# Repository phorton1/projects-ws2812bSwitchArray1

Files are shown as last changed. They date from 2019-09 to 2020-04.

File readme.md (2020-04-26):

# One Wire 3D Printed ws2812b Switch Array

This repository contains the STL and Fusion 360 files used to
create a **3D printed switch** which can be attached to a ws2812 LED
in an array or strip in order to create an array of buttons that
can be sensed by a microprocessor using only **one GPIO pin**.

There are **no multiplexers** involved, and there is **no X-Y grid**
of wires connected to the switches!

It also contains a specific test implementation and demonstration
program (sketch) using a Teensy 3.2 and a commonly available
8x32 LED array.  Below is link to a YouTube video showing the
demonstration program in action, and discussing briefly how the
project works:

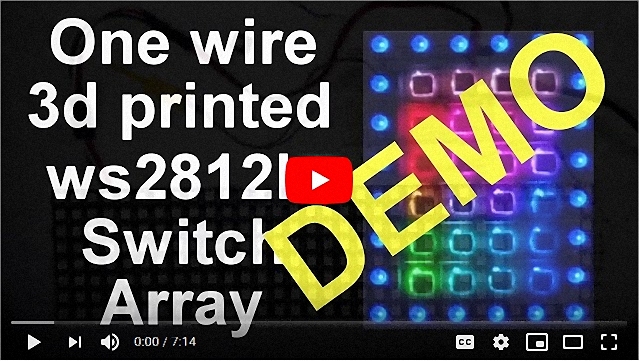
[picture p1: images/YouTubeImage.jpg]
YouTube Video Thumbnail (https://www.youtube.com/watch?v=zrMks7Vt0dI)


**THIS IS ONLY A PROOF OF CONCEPT DEMONSTRATION**

There are a couple of major caveats:

* The technology shown here *may* suffice for DIY purposes, but
  is probably not mature enough, yet, for use in commercial products.
  
* This project is not for the faint-of-heart.  The switches can be
  difficult to print and assemble, requiring the use of a 0.25 or
  smaller nozzle, lowered print speeds, and good filaments. Getting
  the size, and bends, in the guitar string spring/contacts takes
  a lot of patience and at least a few tries.
  
In this repository you can find the STL and Fusion 360 files for
the 3D printed swtiches, along with the source code for the
demonstration program.   Please see the readme files in
the subdirectories for more information:

   [/stl - PRINTING THE SWITCHES](stl/readme.md)

   [/src - THE DEMO PROGRAM](src/readme.md)

This **github repository** is the authorative source of information about this project.
There is also a Hackaday project at [One Wire 3D Printed ws2812 Switch Array](https://hackaday.io/project/167696-one-wire-3d-printed-ws2812b-switch-array)
and a Thingiverse page at [ws2812b Switch](https://www.thingiverse.com/thing:3870539) that contains mostly
the same information, in slightly different presentations.

## HOW THEY WORK

The concept takes advantage of the fact that such LEDs arrays are
fed with a single serial data stream that is successivly passed
down from the first LED in the array to each LED in turn.

Each LED "eats" 24 bits of color information before it begins passing
the subsequent bits onto the next LED.  We also take advantage of the
fact that in the ws2812b protocol every bit, whether a "zero" or a "one"
bit, consists of at least one "rising edge" delivered to each LED.

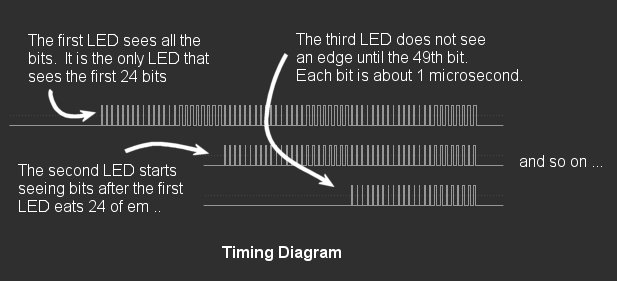
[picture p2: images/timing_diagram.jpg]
Timing Diagram


Thus, by attaching a switch to the DIN (data in) pin of each LED, and
connecting all of those switches to a single common wire back to the
CPU, based on the timing, we can determine which switch, if any, is
pressed during a refresh cycle.

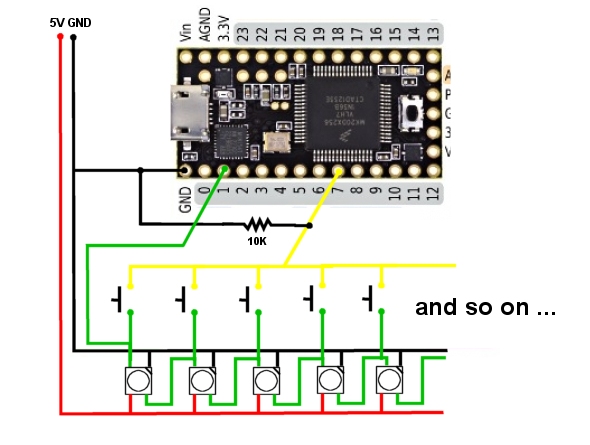
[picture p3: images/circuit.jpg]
Circuit Diagram


The technique can only detect the FIRST button pressed in such an array.
It cannot detect multiple simultaneous button presses. There are other
limitations and issues that will be discussed below.

This example works with an interrupt on the Teensy to measure the
amount of time it takes, from the beginning of a refresh cycle until
the interrupt is triggered to determine which button is pressed.
On the Teensy 3.2 at 90Mhz using the WS2812Serial library, it takes just
about 30 microseconds per LED.  So, basically, we just divide the
number of microseconds to the interrupt by 30 and we get the "button number"
of the (first/earliest) button that is pressed.

This works well in the limited test program, which makes use of the
WS2812Serial, non-blocking, ws2812b library, which in turn uses DMA and
a hardware UART to send the bits to the LEDs. Because it is non-blocking,
and it leaves interrupts enabled, we can use such an approach.

## THIS IDEA SHOULD WORK WITH ANY CPU and/or LIBRARY

Although this demonstration uses the WS2812Serial library and Teensy 3.2,
this concept should be usable with ANY cpu that is currently used to
control such a ws2812b, or other similar, addressable LED array, including
Arduinos and Raspberry Pi's.

**It should also work with different sized arrays, LED strips, circles, etc**

An earlier demonstration of this idea, that used a synchronous detection
approach is available on my previous hackaday page [Why Doesn't Someone Make a ws2812 Switch Array?](https://hackaday.io/page/6514-why-doesnt-someone-make-a-ws2812b-switch-array)

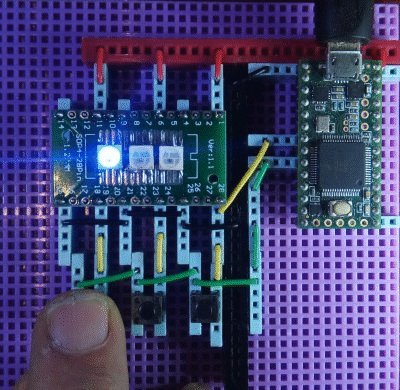
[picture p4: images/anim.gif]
Previous Animation (https://hackaday.io/page/6514-why-doesnt-someone-make-a-ws2812b-switch-array)


In that example, and for other ws2812b libraries, like the FastLEd or Adafruit
NeoPixel libraries, that send the bits to the LEDS synchronously (one by
one via the CPU), an alternative approach can be used if interrupts are
disabled, or if so desired for some other reason.

In that case the low level procedure that sends the bits to the LEDs just
has to have access to a counter that tells it, at any time, which LED
it is sending bits to (each LED takes 24 bits). It can then check the
input line just after it sends out the rising edge of any, or all,
of the bits to each LED, and return the counter as the "number" of
the button that is pressed.

## 3D Printed Switch Issues

Requirements:

* for FDM printers, I think a 0.25 or smaller nozzle may be needed
* a 0.010 high "E" guitar string
* some hemostats or small needle nosed pliers to bend the guitar string

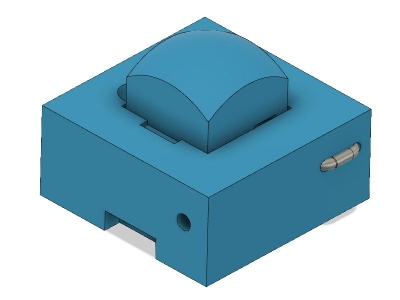
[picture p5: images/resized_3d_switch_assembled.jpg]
3D Switch


### NOZZLE

When I started 3D printing a month or two ago, I immediately went to ebay
and bought a number of inexpensive replacement 0.40 brass nozzles, figuring
I would need them.  At that time I also picked up a variety of different sized
(cheap) stainless steel nozzles for the printer. I think I paid $20 or so for 10
stainless nozzles from 1.0 down to 0.20 mm in size.  I am **not** an expert
at 3D printing and this was my first attempt with a 0.20 nozzle.

You *may* be able to print these with a 0.40 nozzle.  I dunno. I never tried.
I actually started this project by changing the nozzle on the printer and
trying to print really small things for the first time.

### PRINTING TINY THINGS

There are only two printed parts.  The **base** and the **top**.

I will be honest and tell you it was not easy. I found the entire process to
be very finicky.  What would work with one filament would then fail miserably
when I tried it with a different filament.  Or I could get it to print one
switch "base" or "top", but then when I tried (in SlicePE) to print 8 or 16
of the same things, it would fail.  I had to mess around and experiment with
brims and supports, and trying to print the parts every which way.

The current Fusion 360 and STL files are tuned so that they work with my
printer and settings to correctly hold the 0.010 guitar string and 22 guage
wire, so that the switches properly "snap" onto the ws2812 LEDs, and so that
they fit together in an array.

Your mileage may vary!

### THE GUITAR STRING

The other thing is the "spring" and "contact" made out of a single small
piece of a 0.010 guitar string.   I don't have access to any hardware stores
and so I was forced to make do with what I have here on the boat.  As a guitar
player I have bunch of new and old used guitar strings laying around.  I played
around with the different strings E .... B ..... the wire wound G string ... and
found that the **high E string** had just about the right amount of springyness to
work in such a button.

**Cutting and Bending the Guitar String just right is the most difficult part**

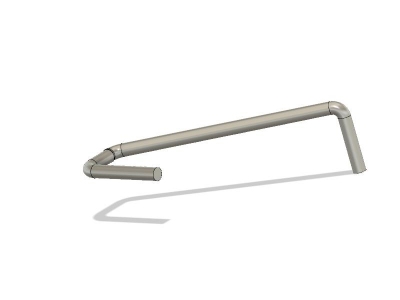
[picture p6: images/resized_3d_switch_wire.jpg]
The Wire


I went through over 20 iterations of the design trying to come up with a way
to (a) make a springy switch and (b) make contact with the DIN pin on each LED,
and (c) connect all the switches together, before narrowing in on this approach.

This approach uses a single small piece of guitar string to meet all three requirements.
The piece of guitar string is both the "spring" for the switch, as
well as the "contact" for the DIN pin, as well as the "connector" to a piece of
22 guiage wire.

Thus it is the most critical piece in the assembly of the switches.

This little piece of wire has to do a lot of work, and must be cut and
bent just right in order to function.

* it has to have a little angle in it so that it acts as a spring to push the button up.
* the other end must be bent and cut just right so that when it is pushed down it makes
  contact with the LED DIN pin
* the holes on the printed switch must be aligned so that the 22 guage wire
  just barely makes conact with the guitar spring when the switch is in an
  "open" position.
  
As I was experimenting, by the time I got it down to one piece of guitar string,
by coincidence, I found that, if the holes were positioned JUST RIGHT, that I
could slide a normal 22 guage solid copper breadboard wire into the holes and they
would make contact with the guitar string in each switch.

In fact, when you press the switch, it pushes down the guitar string down,
re-enforcing the contact with the 22 guage wire first as it then bends down
further to make contact with the DIN pin on the LED.  In this latest (posted)
version of the switch, the 22 guage wire should fit easily into the switches
and when you press the button it should sort of "lock" the 22 guage wire in.

If you find you have to force the 22 guage wire into the hole then you'll
either need to change your print settings, or even go so far as to modify the
design in the Fusion 360 files yourself.

Once again, this is just a "proof of concept". I have some ideas, below,
for future development of more robust and usable switches, possibly involving
printed circuit boards and/or other manufacturing processes..

### ISSUES AND FUTURE IDEAS

* At a minimum each switch needs a diode between the DIN pin on the LED and the
common wire back to the CPU.  Otherwise (with the current circuit) if two buttons
are pressed simultaneously, it connects the two DIN pins, and messes up the serial
data stream.  The switch detection algorithm still works, but the LED array itself
may flash or display the wrong colors as a result of this short circuit.

* I would like to figure out how to "gate" the interrupt signal at each switch
using some kind of a small simple SMD device so that once an interrupt fires,
THAT pin is then disabled from sending any more interrupts.   That would allow
for the detection of multiple simultaneous keypresses.

* I want to explore the use of the ws2812b **2020** LED and custom printed PCB's,
possibly flexible.  The 2020 LED is only 2x2 mm and that would allow a higher
density of switches in the array.  Instead of a 3D printed 10mm switch, I would
then consider tooling up for a (an array of) 4x4 mm soft silicon switch(es).

By the way, this is all (still) nominally part of the
[rPi bare metal Guitar Rig](https://hackaday.io/project/165696-rpi-bare-metal-vguitar-rig) project.
My idea here is to create a **foot-touch-pad** ... like putting a touchscreen on the floor and
using it with your feet.  There are no such (inexpensive) commercially available foot pads,
and there is no way I'm gonna put a $700 iPad on the ground, face up, at a gig, in a bar-room
situation.   I'd like to be able to also get some feedback (i.e. the LED display) about
things like volume levels, patch selections, song position, etc, so I am thinking that a
general purpose controller of this sort could be handy.   It might also be useful for
other purposes, including for use by disabled persons, so it is a project I will continue
to explore.

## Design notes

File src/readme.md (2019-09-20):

# The Software

This directory includes the demo program that I show in the
[One Wire 3D Printed ws2812 Switch Array Demo](https://www.youtube.com/watch?v=qGlxH-YuUHk)
YouTube Video.

If you happen to have a Teensy 3.2 and an 8x32 LED array, then you
*might* be interested in trying to rebuild my exact demo.

**Proabably Not!!** :-)

Really, probably all you really want to know is **how it works** and
**how can I make it work for me** ... :-)

So, although I put a ton of effort into the demo program, sigh, to
implement the color picker and a full blown (although integer)
desktop calculator application :-) all that is actually interesting
in this part of the project is the very small **ws2812SwitchArray class**
that is merely a very thin wrapper around *Paul Stoffregen's*
**WS2812Serial** library.

**IMPORTANT NOTE:**  In the YouTube video I say that I'm using the FastLed
library.  I am not.

I am using **Paul Stoffregen's non-blocking WS2812Serial** library !!

Please support the Teensy and Paul and their website at https://www.pjrc.com!!

## My ws2812SwitchArray class

Here's pretty much the whole H file:

```
#define NUM_ROWS  8
#define NUM_COLS  32
#define NUM_LEDS (NUM_ROWS * NUM_COLS)

class ws2812SwitchArray
{
public:
    
    ws2812SwitchArray();  
    ~ws2812SwitchArray()  {}
    
    void init();
    void showLeds();
 
    void setPixel(int pixel_num, int color);
    void setPixel(int row, int col, int color);
    byte *getDrawingMemory();
    
    int buttonPressed();
        // called at the top of the loop, before the next
        // call to showLeds() and after the previous one,
        // returns the one based button that was pressed,
        // if any.
        
protected:

    static int button_pressed;                     // button pressed 
    static elapsedMicros show_time;                // microseconds since showLeds started
    static void buttonIRQ();

};
```

You call **init()** from your sketch's *setup()* method.

The **setPixel()** and **getDrawingMemory()** methods are just pass
throughs to the the "base class" (global static) leds stuff.
These are used to set the color bytes into arrays in memory.

Each time through your *loop()* method, at some point, you call
**showLeds()** to send the pixels to the array.

Then next time through the loop (at the top) you call **buttonPressed()**
to see if a button was presed during the previous call to showLeds().

*That's pretty much it.*

You may need to modify the number of rows and number of columns to
match your array or strip.   Other details, like the PINS used are
in the CPP file, which is also shown here in nearly it's entirety:

```
#define LED_PIN         1       // write to DIN of first pixel
#define SWITCH_PIN      7       // sense if a button is pressed

// Usable LED pins:
//   Teensy LC:   1, 4, 5, 24
//   Teensy 3.2:  1, 5, 8, 10, 31   (overclock to 120 MHz for pin 8)
//   Teensy 3.5:  1, 5, 8, 10, 26, 32, 33, 48
//   Teensy 3.6:  1, 5, 8, 10, 26, 32, 33

#define MICROS_PER_LED      30      // microseconds per pixel before it sees rising edge
#define MICROS_TO_0TH_LED   475     // microseconds until the first led sees rising edge

byte drawingMemory[NUM_LEDS*3];         //  3 bytes per LED
DMAMEM byte displayMemory[NUM_LEDS*12]; // 12 bytes per LED
WS2812Serial leds(NUM_LEDS, displayMemory, drawingMemory, LED_PIN, WS2812_GRB);

elapsedMicros ws2812SwitchArray::show_time = 0;       // microseconds since showLeds started
int ws2812SwitchArray::button_pressed = 0;            // one based button pressed

ws2812SwitchArray::ws2812SwitchArray() 
{}

void ws2812SwitchArray::init()
{
    pinMode(SWITCH_PIN,INPUT_PULLDOWN);
    attachInterrupt(digitalPinToInterrupt(SWITCH_PIN), buttonIRQ, RISING);
    leds.begin();
}

byte *ws2812SwitchArray::getDrawingMemory()
{
    return drawingMemory;
}

void ws2812SwitchArray::showLeds()
{
    button_pressed = 0;
    show_time = 0;
    leds.show();
}

void ws2812SwitchArray::setPixel(int pixel_num, int color)
    // convenience method
{
    leds.setPixel(pixel_num, color);
}

void ws2812SwitchArray::setPixel(int row, int col, int color)
    // handles interleaving of my led array
{
    if (col % 2) row = NUM_ROWS - 1 - row;
    leds.setPixel(col * NUM_ROWS + row,color);
}

int ws2812SwitchArray::buttonPressed()
{
    return button_pressed;
}

void ws2812SwitchArray::buttonIRQ()
{
    if (!button_pressed)
    {
        int the_time = show_time;
        
        #if 0
            static int counter = 0;
            counter++;
            Serial.print(counter);
            Serial.print(" - IRQ encountered micros=");
            Serial.println(the_time);
        #endif

        button_pressed = ((the_time-MICROS_TO_0TH_LED) / MICROS_PER_LED) + 1;
    }
}
```

In order to calibrate this the first time, I did some measurements to
come up with values for *MICROS_TO_0TH_LED* and *MICROS_PER_LED* by including
the **#if 0** section of code in **buttonIRQ()**

Once more, the code goes like this:

(1) at some point **showLeds()** is called, and it sets both the elapsedMicros "show_time"
and one-based integer variable "button_pressed" to zero.

(2) Then (if a button is pressed) **the IRQ is triggered** and it figures out
which button was pressed and sets that into a button_pressed.

(3) **The client calls buttonPressed()** from their loop() method, at the top
of the next time through their loop, before they make the next showLeds()
call.

There's a bit of debouncing and higher level logic in the
**onLoop()** method in [demo_ui.cpp](demo_ui.cpp), but apart from
that, this is basically how it works.

And finally, please note a couple of other things.

* **This is only a demo**.  It is not intended to be a general purpose library
* The *technique* (but not necesarily the *CODE*) here should work with other CPUs and Libraries
* As an alternative to Interrupts and counting microseconds, for libraries using synchronous
  output or which disable interrupts, you'll have to get down to the low level output method
  and check for a high signal on the input line just after it sends out the rising edge(s).
  At that point, since you are sending out pixels! you should already KNOW what pixel you
  are talking to!

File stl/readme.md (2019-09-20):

# 3D Printed Switches for ws2812b LEDs

This directory contains the STL files for the switches used in the
[One Wire 3D Printed ws2812 Switch Array](../readme.md) project, along
with the **printing** and **assembly** instructions.  You can find
the Fusion 360 files [HERE](https://github.com/phorton1/projects-ws2812bSwitchArray1/tree/master/fusion).

Since they are so small, printing them boils down to an exersize in
trying to print really small things on your printer.

3d_switch
3d_switch_wire

The switch uses a piece of wire (I used a 0.010 high "E" guitar string)
as the spring, contact, and connector.

**The hardest part of the whole project** is to **cut** and **bend** those
pieces of wire **correctly and repeatably**.

It took quite a few tries, but I found that after a while I could do it
reliably and repeatedly

## QUALITY CONTROL

I suggest building one or two, then building 4 or 5, before gearing up for
a production run if you want to try to print and build a lot of these.

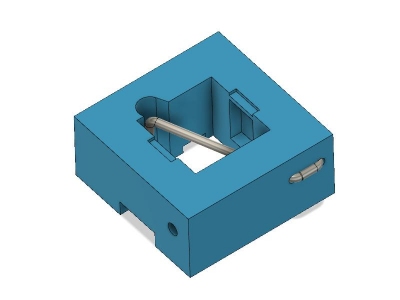
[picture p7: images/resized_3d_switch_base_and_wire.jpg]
3d_switch


Also I recommend assembling and testing them one at a time before stringing
them together into a big array. As I assembled and tested them, I used
three "bins" for the testing results:

* the **"A" bin** contained switches that worked the first time I tried them,
 were nice and springy, and which worked at least a few times reliably,
 in a row, without any gliches.
* the **"B" bin** contained switches that were almost right, but which had **one**
 issue that could probably be solved by popping off the top and tweaking the
 guitar string, but which probably did not need the entire guitar string to
 be replaced, and ...
* the **"C" bin** which contained switches that I should have known would not
 work in the first place.  These are usually ones where the guitar string
 was not bent correctly to begin with, got bent out of shape during
 the assembly process itself, or on which I *missed* the final critical
 bend and trim.   These I had to take the wire out and rebuild from
 scratch.
 
It was fairly rare that once a switch base and top were printed correctly
that they were damaged or made unusable by re-assembly, so I could generally
re-use the 3d printed parts, but it is still a pain to disassemble them, and so,
in the end, it's better to not try to force the issue.

If something doesn't go right during the wire bending and cutting process,
just stop, teke a break, and re-do that one!

The wire is not expensive and you can do the initial bend and cut in less
than 30 seconds ... so you *could* make a hundred or more of them in an
hour.  Better to just start over if it doesn't feel right as you are working!

In any case, only after you are sure that the buttons are working good
should you try to string them together into an array!  If you get a
bad button in the middle of a long string, in the middle of the array,
it can be a real pain to get to that button and fix it!

## PRINTING THE SWITCHES

I generally used a pretty hot **bed at 70C** with the **nozzle at 215C** .. 

I have a **Prusa MK3s** and used an inexpensive chinese
**stainless steel 0.2mm nozzle** with some garden variety
**Mika3D** white **PLA** filament.

I didn't try printing them with the normal 0.4mm nozzle.  It might work
and is certainly worth a try if you don't have a smaller nozzle or
don't want to change yours. I suspect that the smallest nozzle you are
comfortable with should be used.

I printed the **base** upside down (with the bottom up, and the top
on the print surface) at **0.10mm layer height**.  At 10x10 mm it was
just big enough to not require a brim on my printer.

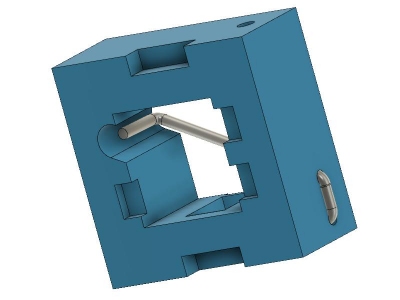
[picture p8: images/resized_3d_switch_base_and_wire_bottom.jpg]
3d_switch


I printed the **top** right side up at **0x05mm layer height**.  As these
are less than 5x5mm, I needed to add a **pretty wide brim** .. 2mm I think ...
around each one so that they would adhere to the print surface.

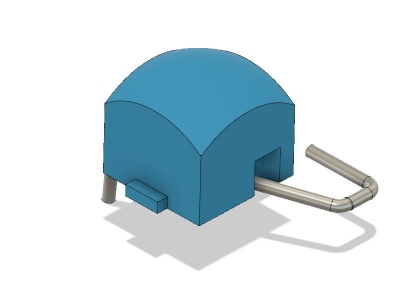
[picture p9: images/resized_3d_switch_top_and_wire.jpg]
3d_switch


I started with the standard Prusa settings for the MK3S with a 0.25 nozzle
and then messed around with those until it worked.   One thing for sure,
you will want to **lower the print speed** signficantly, however you do it.
I went through and modified the default profiles manually usually halfing
any numbers I saw ... printing around 20mm/sec ... lessened accelerations,
etc ... who know!  I'm also using Octoprint and so I diddled with the 
overall "Feed Rate" there as well.

Seems like I **recalibrated the first layer** for each print session.

I also played around with extrusion rates multipliers, elaphant foot
compensation and a host of other things ... sometimes helpful ... sometimes
not ...

I got totally different results and had to re-tune everything when I
changed to some other garden variety black PLA filament.  And when
I tried printing them with some bad-old-transparent PLA that
I have (I live on a **BOAT** in the **TROPICS** lol), it just
resulted in a small bubbly stringy mess and a clogged nozzle
repair session ... so **good filament is a must!**

In one generation I had to sand the sides of the top's to even get them
in the holes.   Then I found I had a jewler's file and used that ...
the next generation they slid in an out with any modification!!

You're probably more of an expert at 3D printing than I am!  I only
started two months ago!

The bottom line is that these are small and cheap, yet difficult and
time consuming to print, and that dialing them in on your printer will
take some effort and that I can't easily tell you how to do it right the
first time. In the end all that is important is (a) that they snap on to
the ws28128 LEDS and don't fall off, (b) the holes and features are about
the right size and in the right place, and (c) that the top moves inside
the base correctly.

I'd like to hear from someone who tries to print these on an SLA
printer.  That would probably work pretty good ... 

## ASSEMBLING THE SWITCHES

There are a number of steps I can detail in the bending of the wire
and assembly of the switch

1. **the initial bend** - itself is in two parts.

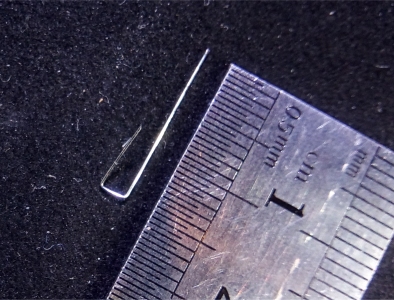
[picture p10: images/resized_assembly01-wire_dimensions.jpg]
assembly 01
   
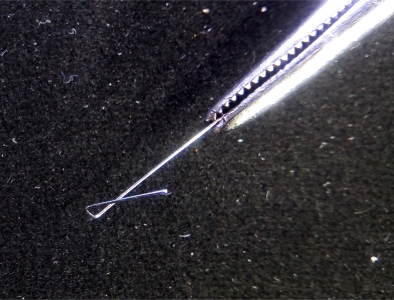
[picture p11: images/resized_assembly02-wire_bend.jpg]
assembly 02
    |

   (note that the pictures above do not show what I'm saying below!!)
   
   First I go about 15mm down from the end of the wire, snap the
   hemostats on the wire with as small a cross section as possible,
   and turn the hemostats top towards me while pulling the wire
   underneath and a bit to the right.  That makes a right angle
   bend with a circular remainder.
   
   Then I take just the tip of the hemostats, hook them into the
   circular part and bend that a little more so that it's got right
   angles with the proper tilt and spacing.
   
2. **cut the piece off of the main wire**  - I then liberate the
  piece from the main wire by cutting it **about 4 mm** from the
  bend.
  
   (NOW the pictures start following the instructions a little
  more closely!!)
  
3. **insert the wire into the switch** - insert the long end of the
  wire into the hole and feed it through so that it comes out the
  top of the switch. It will be under a little bit of tension and
  that's ok, but you should not need to actually BEND the wire
  while inserting it.

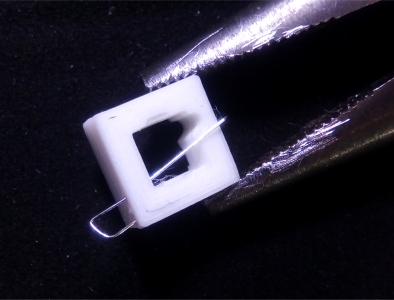
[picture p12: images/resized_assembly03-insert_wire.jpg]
assembly 03
   
  
   Then with the hemostats or a small pair of needle nose pliers
   slightly twist and push the small end of the wire into the
   other hole at the same time you feed the remainder of the long
   part thru.
  
   If all goes well you will be left with a 1mm or so imperfect
   loop outside of the switch.
  
4. **compress the wire into the switch** - I then used small needle
  nose pliers around each side of the switch to do a final **press**
  of the wire into the switch.  If all goes well there should not
  be any play in the main wire .. and no big ugly bent piece of wire
  on the outside of the switch!  It should be nicely seated in the
  switch with a nice little piece of the wire visible on the outside
  of the switch.

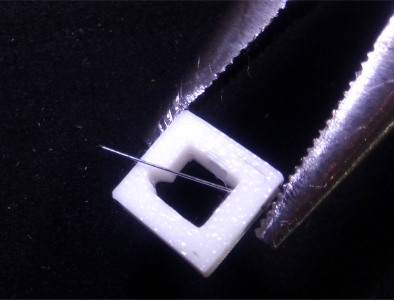
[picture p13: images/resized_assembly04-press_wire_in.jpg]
assembly 04
   
  
5. **trim the wire to about "here"**.  Next I line up the wire diagonally
  with the "down hole" on the switch base while trimming (cutting) it
  flush with the outer edge of the switch (or so).  So at that point the
  wire should exceed the dimension to the hole by about 1 or 1.5mm.

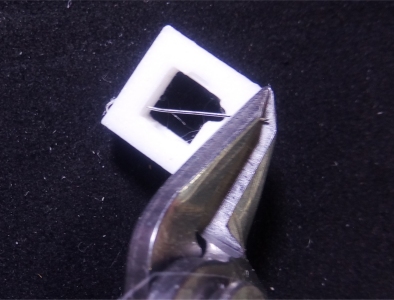
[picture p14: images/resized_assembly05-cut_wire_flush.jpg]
assembly 05
   
  
   Note that in the photo I show some flush cut shears.  **DONT USE
   YOUR FLUSH CUT SHEARS** with the steel guitar string.  It will ruin
   them!  At least if they are like mine (i.e. cheap chinese ones),
   they will not cut steel. Well, they'll cut it, but it will also
   leave a dig in the blade and basically ruin the cutters!
  
   In actuality I used some big-honking (regular sized) wire
   cutters that can handle the steel guitar strings without any
   damage any time I have to cut it!
  
6. **THE CRITICAL DOWN-BEND**.  Now, taking **just the tip** of the
  hemostats, grab the end of the wire and bend it so that it points
  downwards towards or into the "down-hole".   This bend should be
  "just about" 90 degrees, but should definitely not be more!
  
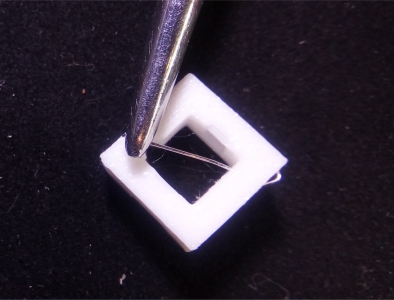
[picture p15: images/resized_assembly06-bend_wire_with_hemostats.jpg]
assembly 06
   
  
   If this critical step goes well, the end of wire will just barely
   not fall down into the hole right after the bend, and you will still
   need to sort of force it in there with an exacto knife or the hemostats.
   Yet, once it is inside the hole, that the wire should be somewhat
   centered in the hole, so that when the button is pressed the wire
   goes down through the hole to make contact with the DIN pin
   of the LED.

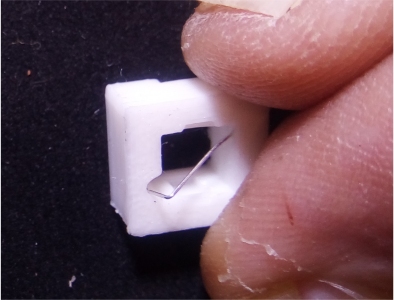
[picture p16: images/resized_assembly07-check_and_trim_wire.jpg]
assembly 07
   
  
   I did say it would take some practice, didn't I?
  
7. **Final Trim** - at that point I usually turn the button upside down,
  press the housing down so that the wire comes up thru the bottom of the
  swtich, and trim the wire so that it is flush with the switch when the
  button is depressed.   Too much and it won't make contact.  Yet you
  want a little play in it.  It **should not** extend to the bottom of
  the switch when the switch is not depressed!

8. **Insert the Top** - You can then insert the top part into the
  switch.  I found this works best by inserting it at an angle,
  with the side nearest the input wire going in first, and then
  turning it as I press the other side into the switch.
  
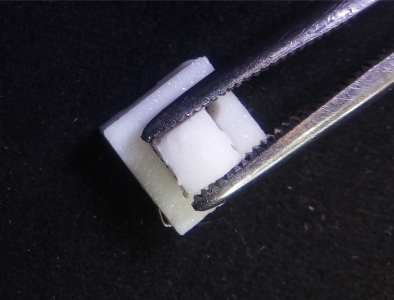
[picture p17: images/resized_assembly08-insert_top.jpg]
assembly 08
   

9. **Insert the 22 guage Wire** and **test it** - at this point
  I insert a piece of 22 guage wire into the switch.  It should
  go in easily, yet with some resistance, while the switch is open.
  Ideally, when the switch is closed you will notice that it is
  firmly stuck in the switch.

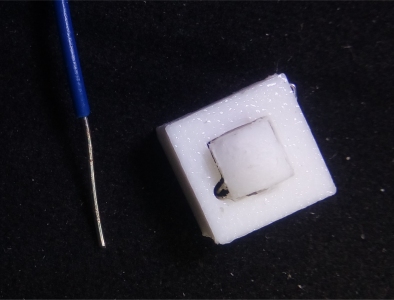
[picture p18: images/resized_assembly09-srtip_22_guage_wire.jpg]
assembly 09
   
  
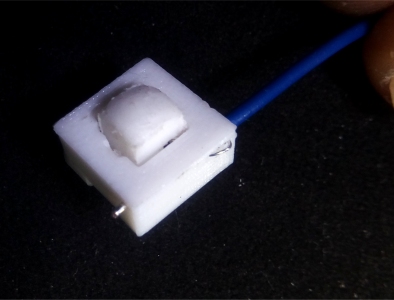
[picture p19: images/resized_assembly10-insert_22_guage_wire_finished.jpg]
assembly 10
   
  
------------------------------------------

### Pop the button on the array and try it!
  
* If it works good, put it in Bin A :-)
* If not, try, try again :-()

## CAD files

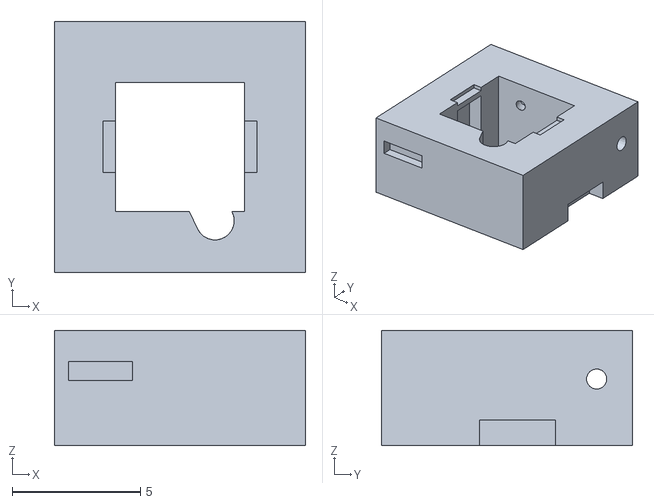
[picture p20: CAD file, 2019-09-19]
stl/switch_base.stl
9.80 x 9.80 x 4.50

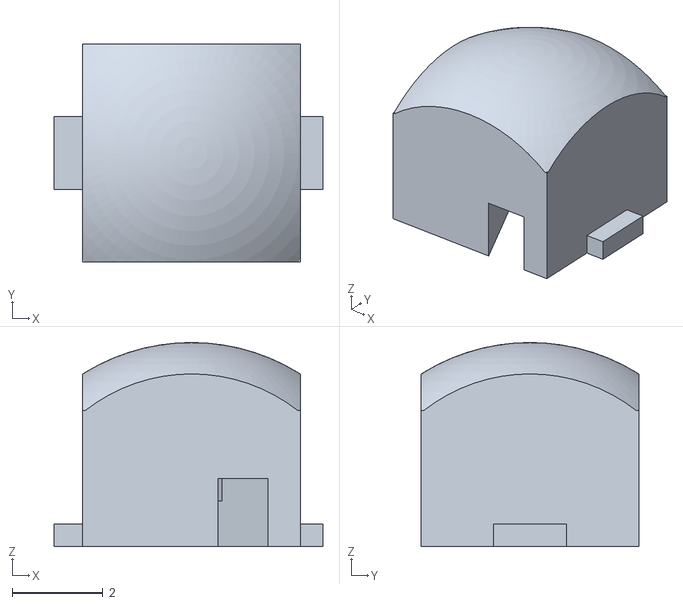
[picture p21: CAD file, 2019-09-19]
stl/switch_top_rounded.stl
5.93 x 4.80 x 4.50

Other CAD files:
fusion/w2812bSwitch.f3d

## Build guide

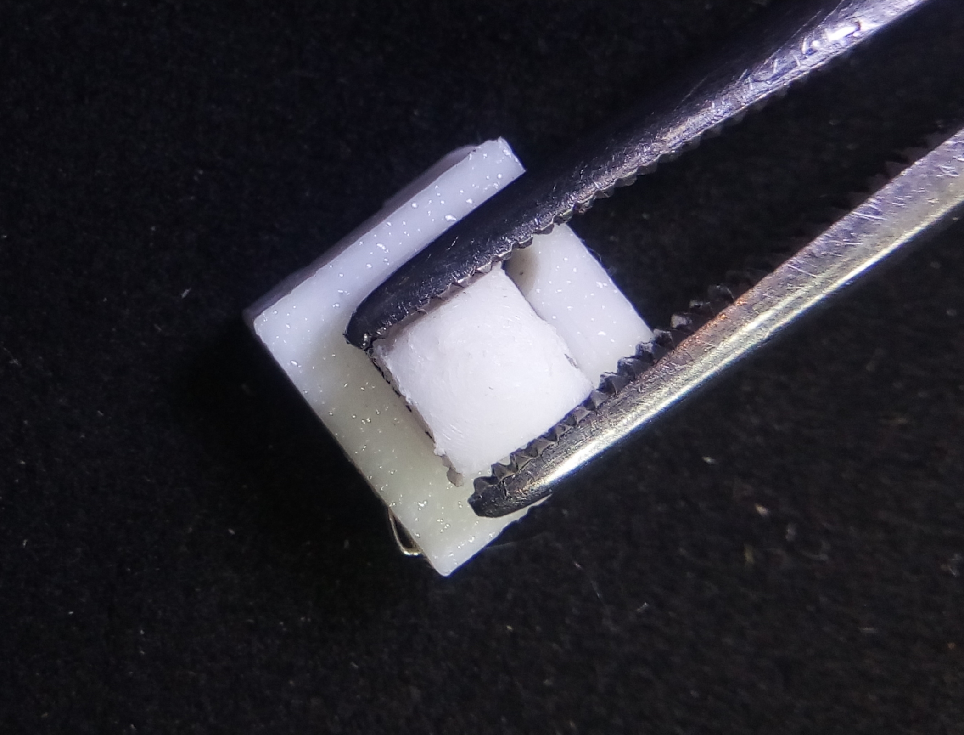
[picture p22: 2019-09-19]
docs/images/assembly08-insert_top.jpg

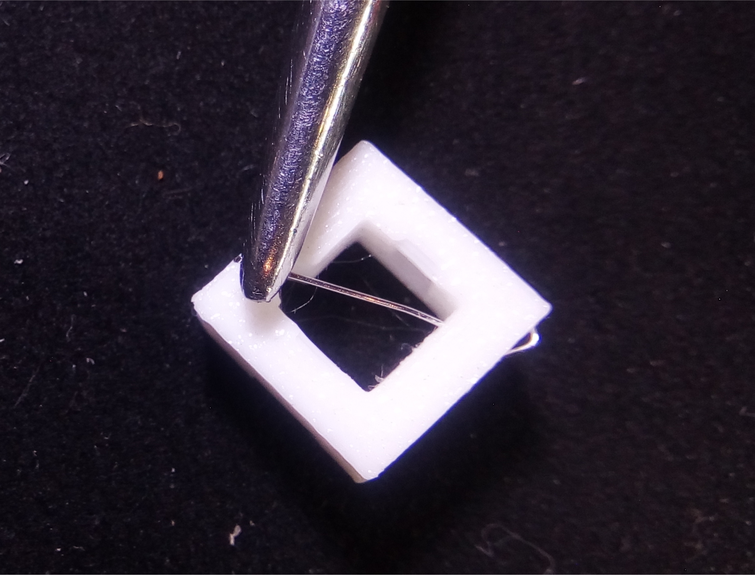
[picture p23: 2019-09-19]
docs/images/assembly06-bend_wire_with_hemostats.jpg

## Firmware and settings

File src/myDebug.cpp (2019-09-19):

//------------------------------------------
// button and expression pedal routines
//------------------------------------------

#include "myDebug.h"

int debug_level = 0;
int warning_level = 0;

// string is "\033[%d;" with following
// ansi color codes fore back
//  
//     Black 	        30 	40 
//     Red 	            31 	41 
//     Green 	        32 	42 
//     Yellow 	        33 	43   brown
//     Blue 	        34 	44 
//     Magenta 	        35 	45 
//     Cyan 	        36 	46 
//     White 	        37 	47 
//     Bright Black 	90 	100
//     Bright Red 	    91 	101
//     Bright Green 	92 	102
//     Bright Yellow 	93 	103
//     Bright Blue 	    94 	104
//     Bright Magenta 	95 	105
//     Bright Cyan 	    96 	106
//     Bright White 	97  107

#define COLOR_CONST_NONE     0
#define COLOR_CONST_WARNING  1
#define COLOR_CONST_ERROR    2

#define DISPLAY_BUFFER_WARNING   10
    // will get a warning before we use a format that is
    // this close to the full buffer size.


#ifdef CORE_TEENSY
    #define DISPLAY_BUFFER_SIZE     255
    #define PLATFORM_COLOR_STRING   "\033[92m"      // bright green    
    #define WARNING_COLOR_STRING    "\033[93m"       // yellow   
    #define ERROR_COLOR_STRING      "\033[91m"       // red   
#else
    #define DISPLAY_BUFFER_SIZE     80
    #define PLATFORM_COLOR_STRING   "\033[96m"       // bright cyan
    #define WARNING_COLOR_STRING    "\033[33m"       // brown
    #define ERROR_COLOR_STRING      "\033[95m"       // magenta
#endif


#if WITH_DISPLAY || WITH_WARNINGS || WITH_ERRORS
    char display_buffer1[DISPLAY_BUFFER_SIZE];
    #if USE_PROGMEM
        char display_buffer2[DISPLAY_BUFFER_SIZE];
    #endif
#endif


#if WITH_INDENTS
    int proc_level = 0;
    void indent()
    {
        for (int i=0; i<proc_level; i++)
            dbgSerial.print("    ");
    }
#endif


#if WITH_DISPLAY
    void clearDisplay()
    {
        dbgSerial.print("\033[2J");
        dbgSerial.print("\033[3J");
    }

    void display_fxn(int level, const char *format, ...)
    {
        checkMem();
        
        if (level > debug_level)
            return;
        
        va_list var;
        va_start(var, format);
        
        #if USE_PROGMEM
            if (strlen_P(format) >= DISPLAY_BUFFER_SIZE)
            {
                dbgSerial.println(F("error - display progmem buffer overflow"));
                return;
            }
            strcpy_P(display_buffer2,format);
            vsprintf(display_buffer1,display_buffer2,var);
        #else
            if (strlen(format) >= DISPLAY_BUFFER_SIZE)
            {
                dbgSerial.println(F("error - display buffer overflow"));
                return;
            }
            vsprintf(display_buffer1,format,var);
        #endif

        dbgSerial.print(PLATFORM_COLOR_STRING);
        #if WITH_INDENTS
            indent();
        #endif
        dbgSerial.println(display_buffer1);
    }
#endif


#if WITH_WARNINGS
    void warning_fxn(int level, const char *format, ...)
    {
        checkMem();

        if (level > warning_level)
            return;
        
        va_list var;
        va_start(var, format);

        #if USE_PROGMEM
            if (strlen_P(format) >= DISPLAY_BUFFER_SIZE)
            {
                dbgSerial.println(F("error - warning progmem buffer overflow"));
                return;
            }
            strcpy_P(display_buffer2,format);
            vsprintf(display_buffer1,display_buffer2,var);
        #else
            if (strlen(format) >= DISPLAY_BUFFER_SIZE)
            {
                dbgSerial.println(F("error - warning buffer overflow"));
                return;
            }
            vsprintf(display_buffer1,format,var);
        #endif

        dbgSerial.print(WARNING_COLOR_STRING);
        #if WITH_INDENTS
            indent();
        #endif
        dbgSerial.print("WARNING - ");
        dbgSerial.println(display_buffer1);
    }
#endif



#if WITH_ERRORS
    void error_fxn(const char *format, ...)
    {
        checkMem();

        va_list var;
        va_start(var, format);
        
        #if USE_PROGMEM
            if (strlen_P(format) >= DISPLAY_BUFFER_SIZE)
            {
                dbgSerial.println(F("error - error progmem buffer overflow"));
                return;
            }
            strcpy_P(display_buffer2,format);
            vsprintf(display_buffer1,display_buffer2,var);
        #else
            if (strlen(format) >= DISPLAY_BUFFER_SIZE)
            {
                dbgSerial.println(F("error - error buffer overflow"));
                return;
            }
            vsprintf(display_buffer1,format,var);
        #endif

        dbgSerial.print(ERROR_COLOR_STRING);
        dbgSerial.print("ERROR - ");
        dbgSerial.println(display_buffer1);
    }
#endif



    // defined even if MY_DEBUG is turned off

uint8_t myButtonPressed(uint8_t pin, uint8_t *state)
    // available if !MY_DEBUG
{
    checkMem();
    
    if (digitalRead(pin))
    {
        if (*state)
        {
            *state = 0;
        }
    }
    else if (!*state)
    {
        *state = 1;
        return 1;
    }
    return 0;
}





#if OLD_STUFF

    //-------------------------
    // hex display routines
    //-------------------------
    // use 4 buffers so they can be
    // called from my display macros
    
    #define NUM_HEX_BUFS  4
    char hex_buf[NUM_HEX_BUFS][10];
    int next_hex_buf = 0;
    
    char *hex2(uint8_t v)
    {
        int bnum = next_hex_buf++;
        sprintf(hex_buf[bnum],"0x%02x",v);
        if (next_hex_buf>=NUM_HEX_BUFS) next_hex_buf=0;
        return hex_buf[bnum];
    }
    
    char *hex4(uint16_t v)
    {
        int bnum = next_hex_buf++;
        sprintf(hex_buf[bnum],"0x%04x",v);
        if (next_hex_buf>=NUM_HEX_BUFS) next_hex_buf=0;
        return hex_buf[bnum];
    }
    
    char *hex8(uint32_t v)
    {
        int bnum = next_hex_buf++;
        sprintf(hex_buf[bnum],"0x%08lx",v);
        if (next_hex_buf>=NUM_HEX_BUFS) next_hex_buf=0;
        return hex_buf[bnum];
    }
    
    
    //-------------------------
    // rest of API
    //-------------------------
    
    void init_my_debug()
    {
        dbgSerial.begin(MY_BAUD_RATE);
        checkMem();
    }
    
    void clearPutty()
    {
        // dbgSerial.print("\033[1;1]f");
        // dbgSerial.print("\033[1J");
        dbgSerial.print("\033[2J");
        dbgSerial.print("\033[3J");
        
    }
#endif
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

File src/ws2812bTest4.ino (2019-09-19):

// Based on Teensy WS2812Serial BasicTest Example
//
// Test ws2812b switch array
//
// Attach the DIN pin(s) of ws2812b's thru a switch to
// a common bus to SWITCH_PIN, and when the corresponding
// pixel gets a signal (rising edge), if the button is pressed,
// it will generate an interrupt.  From that interrupt we can
// determine which button, if any, was pressed.
//
// I use a 10K pulldown resister on the SWITCH_PIN.
//
// Otherwise, it uses Paul's well documented and well written
// WS2812Serial.h library to write the pixels and a hodge-podge
// of other stuff to present a flashy UI.
//
// I made a 3D printed button that snaps on top of ws2812's on
// these ws3812 arrays.  Please see Hackaday for the STl files.
//
// The main problem with this approach is that (a) it cannot detect
// multiple button presses, and (b) if there ARE multiple buttons pressed
// simultaneously, the DIN pins will be connnected together and the LED's
// will not work correctly.
//
// (b) can be solved by merely putting a diode between the switch
// and the bus line so that the signal only goes one way.
//
// As I'm planning to make a foot pedal midi controller, I think
// that (a) can be mostly mitigated by dividing the array into
// two parts (left and right).  So, the right foot could, for example,
// press a "shift" key, and the left foot could select a functionn.
//
// Perhaps someone can think of a way to get around detecting multiple
// simultaneous keypresses.


#include "demo_ui.h"
#include "myDebug.h"

demoUI ui;


void setup()
{
    Serial.begin(115200);
    delay(1000);
    display(0,"started ...",0);
    ui.init();
}


void loop()
{
    ui.onLoop();
}   
